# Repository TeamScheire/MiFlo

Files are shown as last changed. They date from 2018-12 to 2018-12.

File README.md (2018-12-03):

# Team Scheire MiFlo's voor Minne en Flo

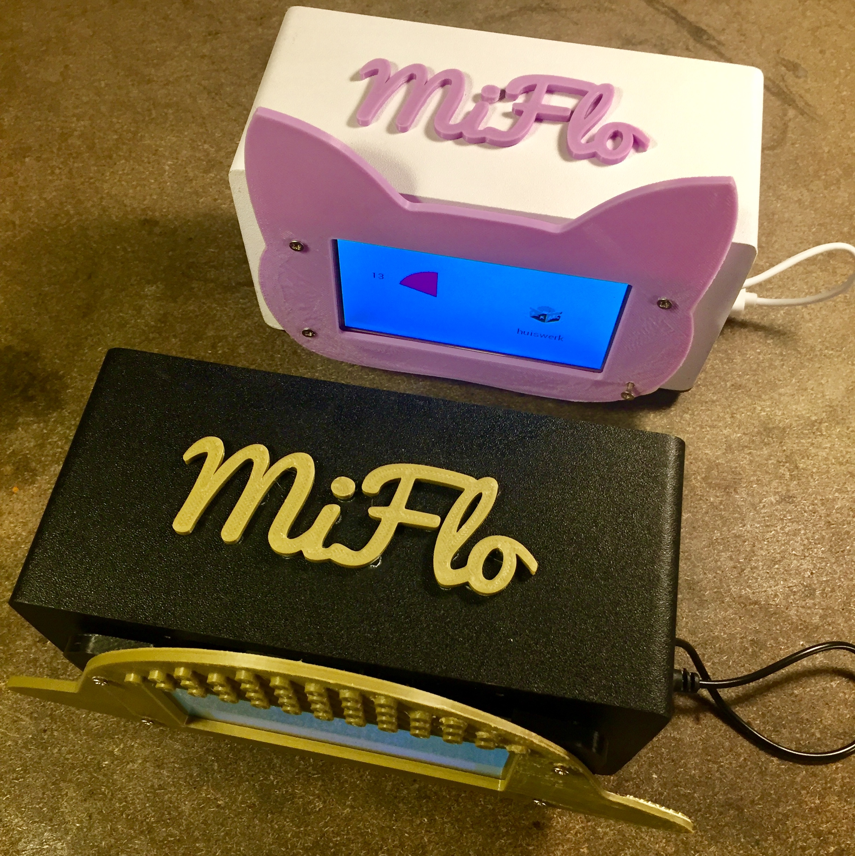
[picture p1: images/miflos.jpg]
Miflo's


Met hun MiFlo kregen Minne en Flo hun eigen persoonlijke digitale assistent.

De MiFlo is een wekker die aan het internet hangt. Mama en papa kunnen via chat of hun online kalender todo's, herinneringen, wekkers of time-timers klaarzetten voor de kinderen.

Door opdrachtjes uit te voeren krijgen de kinderen punten en "gamifyen" we hun dagdagelijkse schema.

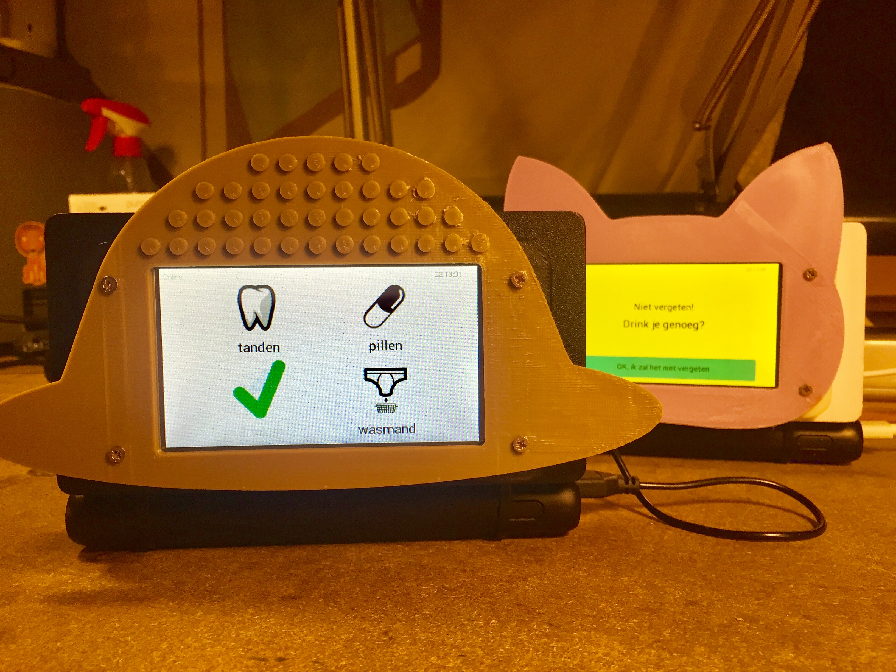
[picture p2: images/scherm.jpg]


Deze repository bevat alle onderdelen die je nodig hebt om zelf een MiFlo te bouwen. 

Een beetje handigheid met Arduino's en elektronische componenten is wel nodig als je zelf een miflo wekker wil maken.

* Onder [hardware](./hardware) kan je een BOM vinden van de materialen die gebruikt werden. Het bevat ook het PCB design en de files om de 3D prints te maken.
* Onder [arduino](./arduino) kan je de code vinden die op de MiFlo's draait. 
* Onder [assets](./assets) vind je de iconen en geluiden die op de SD kaart van de MiFlo staan.
* Onder [backend](./backend) vind je de code die de MiFlo's vanuit het internet controleert. Je kan met Telegram opdrachten naar de MiFlo sturen. Of je kan in Google calendar opdrachten klaarzetten die dan elke 5 minuten worden opgehaald en doorgegeven worden aan de MiFlo's.

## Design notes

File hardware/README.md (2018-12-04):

# Hardware voor de MiFlo

De hardware in de MiFlo is opgebouwd op eenvoudig verkrijgbare modules:

* Een [Adafruit Feather HUZZAH](https://learn.adafruit.com/adafruit-feather-huzzah-esp8266) wordt gebruikt als de "Arduino". Deze bevat een ESP8266 chip waarmee we ook WiFi kunnen gebruiken
* De [Gameduino 3](http://excamera.com/sphinx/gameduino3/) is een touchscreen dat je makkelijk op een Arduino kan monteren en aansturen. Het kan ook geluiden of filmpjes spelen van een SD kaart. Bijvoorbeeld [hier te koop](https://www.watterott.com/de/Gameduino-3).
* Met een [RTC breakout board](https://www.adafruit.com/product/3295) kunnen we de tijd bijhouden als de MiFlo geen stroom heeft.
* Een [geluidsversterker](https://www.adafruit.com/product/1752) zorgt ervoor dat de audio krachtig genoeg uit de speakers komt.
* We bouwden alles in een [SoundLogic draagbare speaker](https://www.action.com/nl-be/p/soundlogic-draagbare-speaker/) van den Action.

We ontwierpen zelf een PCB die deze componenten allemaal bij elkaar brengt, deze vind je (als `.brd` en `.sch` files voor Autodesk EAGLE) in deze repository. Met de PCB kan je zowel een klassieke Arduino of een Adafruit Feather verbinden met het Gameduino touchscreen.

Om de MiFlo mooi te bevestigen printten we kittenoortjes voor Minne en een Lego-helm voor Flo. Samen met 2 clips kan je de MiFlo zo bevestigen in de draagbare speakerkast. Je vindt deze STL files om zelf te printen als `kat.stl`, `legohelm.stl` en `clip.stl`.

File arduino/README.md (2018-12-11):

# Arduino code voor de MiFlo

Deze code is geschreven voor een [Adafruit Feather HUZZAH ESP8266](https://learn.adafruit.com/adafruit-feather-huzzah-esp8266) in combinatie met een [gameduino touchscreen](https://www.watterott.com/en/Gameduino-3). 

Bekijk in de [hardware](../hardware) folder van dit project de volledige hardware lijst.

## Configuratie en setup

Alle details over de Adafruit Feather HUZZAH ESP8266 staan op [de site van adafruit](https://learn.adafruit.com/adafruit-feather-huzzah-esp8266/using-arduino-ide).

Kopiëer het bestand `settings_example.h` naar `settings.h` en vul alle parameters in.

Je hebt ook de volgende libraries nodig:

* [gameduino](https://github.com/jamesbowman/gd2-lib)
* arduino EEPROM library
* [RTC](https://github.com/adafruit/RTClib) library.
* [ArduinoJson](https://github.com/bblanchon/ArduinoJson)

In de gameduino library moet je enkele aanpassingen doen in de GD2.file:

*  Voeg
	
	```
	#define D8  0
	#define D9  16
	```
	toe net voor de lijn `#define CS D8`.
* Zoek naar `#define L2` en `#define L4` en comment deze lijnen.

De arduino code gaat ervanuit dat je de geconverteerde [assets](../assets) mee op de sd kaart gezet hebt.

In de code wordt bv de header-file `m_cool.h` geladen.

```
#include "m_cool.h"
```

Daarnaast worden ook alle pictogrammen geladen:

```
void load_jpgs() 
{
	GD.BitmapHandle(BRIL_JPG);
	GD.cmd_loadimage(ASSETS_END, 0);
	GD.load("BRIL.jpg");

	...
	
}
```

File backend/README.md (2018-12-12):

# MiFLo backend

These two tools send commands to the MiFlo. One is a Google Calendar script that sends the 5 upcoming events on a calendar to the MiFlo, to be cached and executed when planned. The second is a Telegram bot that listens to commands over Telegram and forwards them to the MiFLo.

## Calendar

Follow ruby calendar quickstart at [https://developers.google.com/calendar/quickstart/ruby] (https://developers.google.com/calendar/quickstart/ruby) to obtain credentials in the form of a `client_secret.json` file so you can run the example:

`ruby calendar.rb -c CALENDAR_ID -p PERSON_NAME -h MQTT_BROKER`

## Telegram bot

Get a Telegram bot up and running, acquire the token and run the MiFlo bot:

`ruby telegram_bot.rb -h MQTT_BROKER -t TELEGRAM_BOT_TOKEN -p PERSON_NAME`

## Example installation rapsberry pi

The backend can run on any server, but here is a small example on how to do it on a raspberry pi:

* Install raspbian [https://www.raspberrypi.org/downloads/raspbian/](https://www.raspberrypi.org/downloads/raspbian/)
* Using `sudo raspi-config` you can adapt some basic settings (e.g. enable ssh, change hostname, update, ...), do not forget to correct the timezone
* `sudo apt-get update`
* install git: `sudo apt-get install git`
* clone the repo `git clone https://github.com/TeamScheire/MiFlo.git`
* `cd MiFlo/backend`
* install ruby: 
 ```
 sudo apt-get install ruby
 sudo gem install bundler
 bundle install
 ```
* install mosquitto broker:
 ```
 sudo wget https://repo.mosquitto.org/debian/mosquitto-repo.gpg.key
 sudo apt-key add mosquitto-repo.gpg.key
 cd /etc/apt/sources.list.d/
 sudo wget http://repo.mosquitto.org/debian/mosquitto-stretch.list
 sudo apt-get update
 sudo apt-get install mosquitto mosquitto-clients
 ```

* get the calender up and running
 * Follow ruby calendar quickstart at [https://developers.google.com/calendar/quickstart/ruby] (https://developers.google.com/calendar/quickstart/ruby) to obtain credentials in the form of a `client_secret.json`
 * copy/rename the `client_secret.json` to the backend folder, e.g. using `scp`
 * test the calender script `ruby calendar.rb -c CALENDAR_ID -p PERSON_NAME -h localhost` 
  where CALENDER_ID can be found in the settings of the google calender
 * add it to crontab `crontab -e`
 * e.g. every 5 minutes: `*/5 * * * * script -c "cd /home/pi/MiFlo/backend/; ruby calendar.rb -c CALENDAR_ID -p PERSON_NAME -h localhost" /home/pi/MiFlo/backend/calendar.log`
* get the telegram bot up and running
 * create a new bot: `https://core.telegram.org/bots#6-botfather` 
 * test the script `ruby telegram_bot.rb -h localhost -t TELEGRAM_BOT_TOKEN -p PERSON_NAME
 * start on startup: `sudo nano /etc/rc.local`
 * add line `ruby /home/pi/MiFlo/backend/telegram_bot.rb -h localhost -t TELEGRAM_BOT_TOKEN -p PERSON_NAME & > /home/pi/MiFlo/backend/telegram_bot.log  2>&1`

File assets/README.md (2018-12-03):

# MiFlo assets

De assets (afbeeldingen en geluidsfragmenten) voor op de SD card van de MiFlo.

Om deze te kunnen gebruiken, moeten deze geconverteerd worden. 
In deze readme staan de instructies voor linux/mac.

## Conversie van de afbeeldingen

Via het `convert` pakket. Bijvoorbeeld te installeren via apt (linux) of [brew](https://brew.sh/index_nl) (mac).

Zie [convert.sh](convert.sh) voor een bash script.

## Conversion van de audio

de [gameduino2 library](https://github.com/jamesbowman/gd2-lib) heeft de nodige conversietools aan boord om deze audio om te zetten in zogenaamde headers. 

### install gameduino library

```
sudo easy_install -U gameduino2
``` 

### generate headers with following code

```
gd3asset -3 -f all.gd2 -o all.h f_bol.wav f_uitst.wav g_cool.wav g_formid.wav g_machti.wav g_stieva.wav g_woew.wav m_flink2.wav m_spinne.wav f_dduim.wav f_wauw.wav g_dduim2.wav g_goed.wav g_muppet.wav g_super.wav g_woop.wav m_flink3.wav m_super.wav f_go.wav g_allez.wav g_demax.wav g_goedzo.wav g_prima.wav g_tsjing.wav g_zogoed.wav m_gewel.wav f_komaan.wav g_bol.wav g_fantas.wav g_hopla.wav g_scool.wav g_wiii.wav m_flink.wav m_goed.wav
gd3asset -3 -f minne.gd2 -o minne.h m_flink3.wav m_super.wav m_gewel.wav m_flink.wav m_goed.wav m_flink2.wav m_spinne.wav
gd3asset -3 -f flo.gd2 -o flo.h f_dduim.wav f_wauw.wav f_bol.wav f_uitst.wav f_go.wav f_komaan.wav
gd3asset -3 -f genflo.gd2 -o genflo.h f_dduim.wav f_wauw.wav f_bol.wav f_uitst.wav f_go.wav f_komaan.wav g_cool.wav g_formid.wav g_machti.wav g_stieva.wav g_woew.wav g_dduim2.wav g_goed.wav g_muppet.wav g_super.wav g_woop.wav g_allez.wav g_demax.wav g_goedzo.wav g_prima.wav g_tsjing.wav g_zogoed.wav g_bol.wav g_fantas.wav g_hopla.wav g_scool.wav g_wiii.wav
gd3asset -3 -f genminne.gd2 -o genminne.h g_cool.wav g_formid.wav g_machti.wav g_stieva.wav g_woew.wav g_dduim2.wav g_goed.wav g_muppet.wav g_super.wav g_woop.wav g_allez.wav g_demax.wav g_goedzo.wav g_prima.wav g_tsjing.wav g_zogoed.wav g_bol.wav g_fantas.wav g_hopla.wav g_scool.wav g_wiii.wav m_flink3.wav m_super.wav m_gewel.wav m_flink.wav m_goed.wav m_flink2.wav m_spinne.wav
```

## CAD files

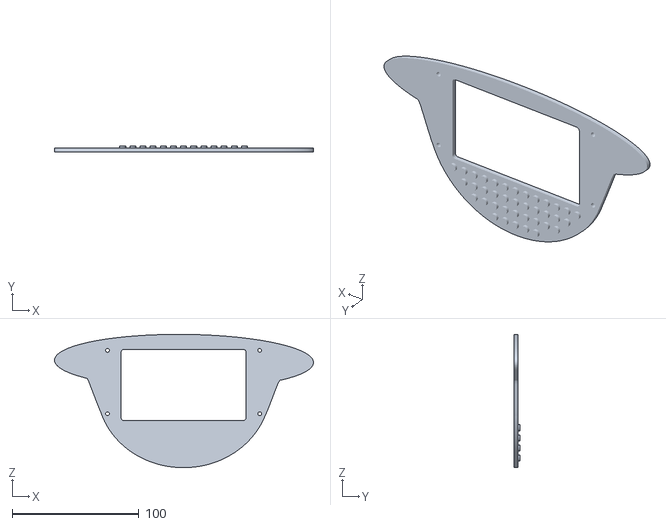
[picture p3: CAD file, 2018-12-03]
hardware/legohelm.stl
204.3 x 4.80 x 105.1

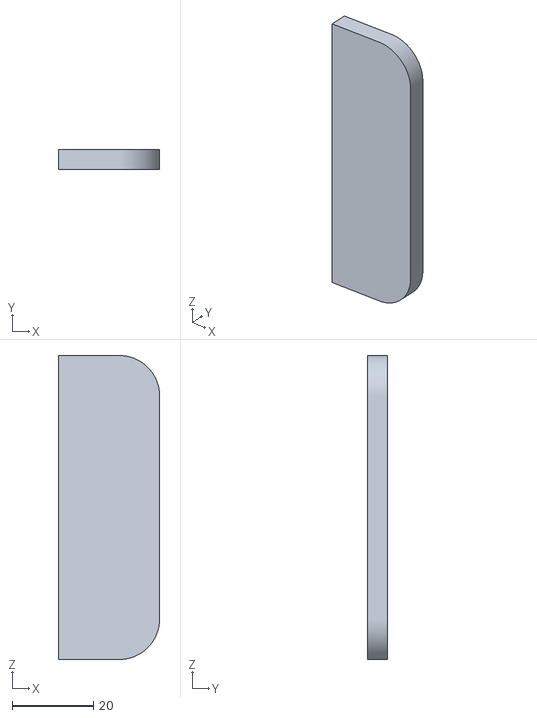
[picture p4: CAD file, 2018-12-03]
hardware/clip.stl
25.0 x 5.00 x 75.0

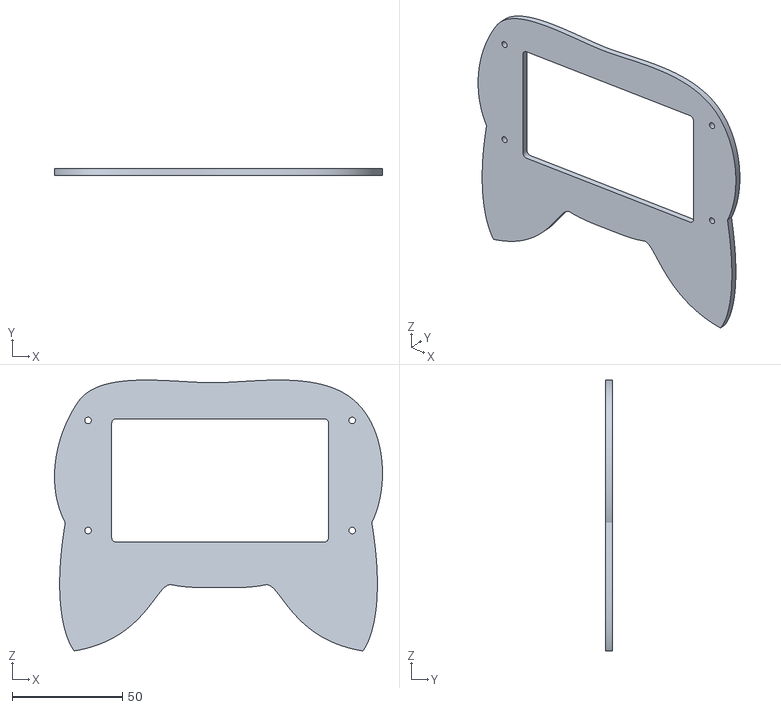
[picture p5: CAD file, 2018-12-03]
hardware/kat.stl
149.0 x 3.00 x 123.1

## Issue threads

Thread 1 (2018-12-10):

Ontbrekende libraries in Eagle

Sharp6, 2018-12-10:
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

Ik probeer de miflo.brd in Eagle te openen om de hardware connecties beter te begrijpen. Eagle klaagt hierbij over enkele missing libraries (FriedCamp en Anthony's components). Kunnen deze nog voorzien worden, of is de impact hiervan beperkt?

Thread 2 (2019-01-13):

Printing/Etching of the PCB

yhellowt, 2019-01-13:
Wat is de meest eenvoudige manier om de PCB te maken?

mstrdigi, 2019-03-20:
Hey, ik heb deze besteld bij Aisler. Het bordje zou deze week aankomen.
Ik heb het project op publiek gezet, zodat je deze ook kan bekijken/bestellen.
https://aisler.net/p/PNIKGYLV

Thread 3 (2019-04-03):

Link soundversterker verwijst naar verkeerde type?

RobinR1, 2019-04-03:
In [hardware/README.md](https://github.com/TeamScheire/MiFlo/blob/master/hardware/README.md) wordt verwezen naar een [Stereo 20W Class D Audio Amplifier - MAX9744](https://www.adafruit.com/product/1752) maar de voorziene pin-layout op de PCB komt exact overeen met een [Adafruit Mono 2.5W Class D Audio Amplifier - PAM8302](https://www.adafruit.com/product/2130).
Is de link in [hardware/README.md](https://github.com/TeamScheire/MiFlo/blob/master/hardware/README.md) verkeerd?

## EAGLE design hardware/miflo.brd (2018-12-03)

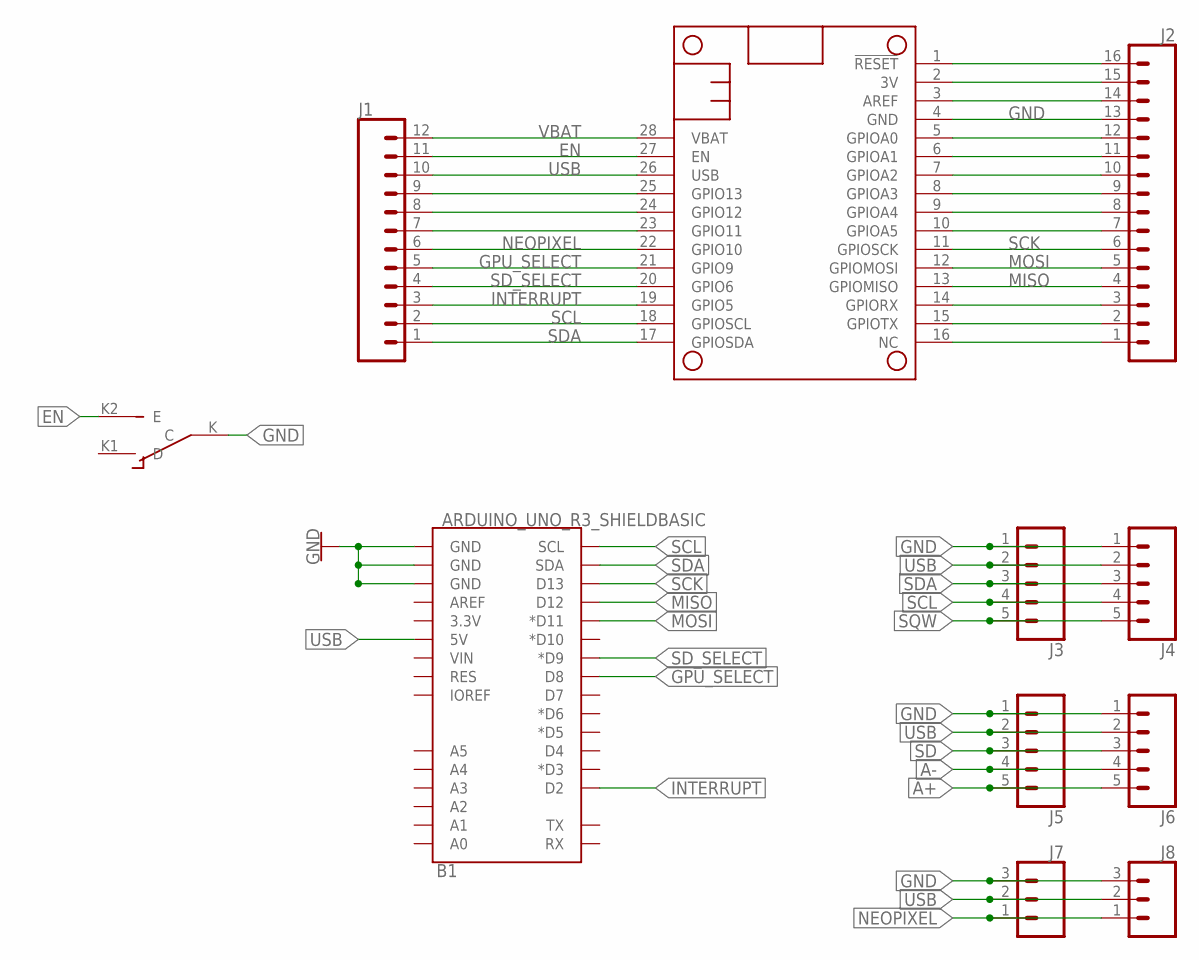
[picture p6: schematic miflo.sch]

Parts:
B1: ARDUINO_UNO_R3_SHIELDBASIC; UNO_R3_SHIELD
J1: CONN_12; 1X12
J2: CONN_16; 1X16
J3, J4, J5, J6: CONN_05; 1X05
J7, J8: CONN_03; 1X03
MS2: FEATHERWING_NODIM; FEATHERWING_DIM
U$11: SLIDE-SWITCH

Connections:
3V: J2.15, MS2.2 (3V)
A+: J5.5, J6.5
A-: J5.4, J6.4
EN: J1.11, MS2.27 (EN), U$11.K2 (E)
GND: B1.GND@0 (GND), B1.GND@1 (GND), B1.GND@2 (GND), J2.13, J3.1, J4.1, J5.1, J6.1, J7.3, J8.3, MS2.4 (GND), U$11.K (C)
GPU_SELECT: B1.D8, J1.5, MS2.21 (GPIO9)
INTERRUPT: B1.D2, J1.3, MS2.19 (GPIO5)
MISO: B1.D12, J2.4, MS2.13 (GPIOMISO)
MOSI: B1.D11 (*D11), J2.5, MS2.12 (GPIOMOSI)
unnamed: J1.9, MS2.25 (GPIO13)
unnamed: J1.8, MS2.24 (GPIO12)
unnamed: J1.7, MS2.23 (GPIO11)
unnamed: J2.1, MS2.16 (NC)
unnamed: J2.2, MS2.15 (GPIOTX)
unnamed: J2.3, MS2.14 (GPIORX)
unnamed: J2.7, MS2.10 (GPIOA5)
unnamed: J2.8, MS2.9 (GPIOA4)
unnamed: J2.9, MS2.8 (GPIOA3)
unnamed: J2.10, MS2.7 (GPIOA2)
unnamed: J2.11, MS2.6 (GPIOA1)
unnamed: J2.12, MS2.5 (GPIOA0)
unnamed: J2.14, MS2.3 (AREF)
unnamed: J2.16, MS2.1 (!RESET)
NEOPIXEL: J1.6, J7.1, J8.1, MS2.22 (GPIO10)
SCK: B1.D13, J2.6, MS2.11 (GPIOSCK)
SCL: B1.SCL, J1.2, J3.4, J4.4, MS2.18 (GPIOSCL)
SD: J5.3, J6.3
SDA: B1.SDA, J1.1, J3.3, J4.3, MS2.17 (GPIOSDA)
SD_SELECT: B1.D9 (*D9), J1.4, MS2.20 (GPIO6)
SQW: J3.5, J4.5
USB: B1.5V, J1.10, J3.2, J4.2, J5.2, J6.2, J7.2, J8.2, MS2.26 (USB)
VBAT: J1.12, MS2.28 (VBAT)

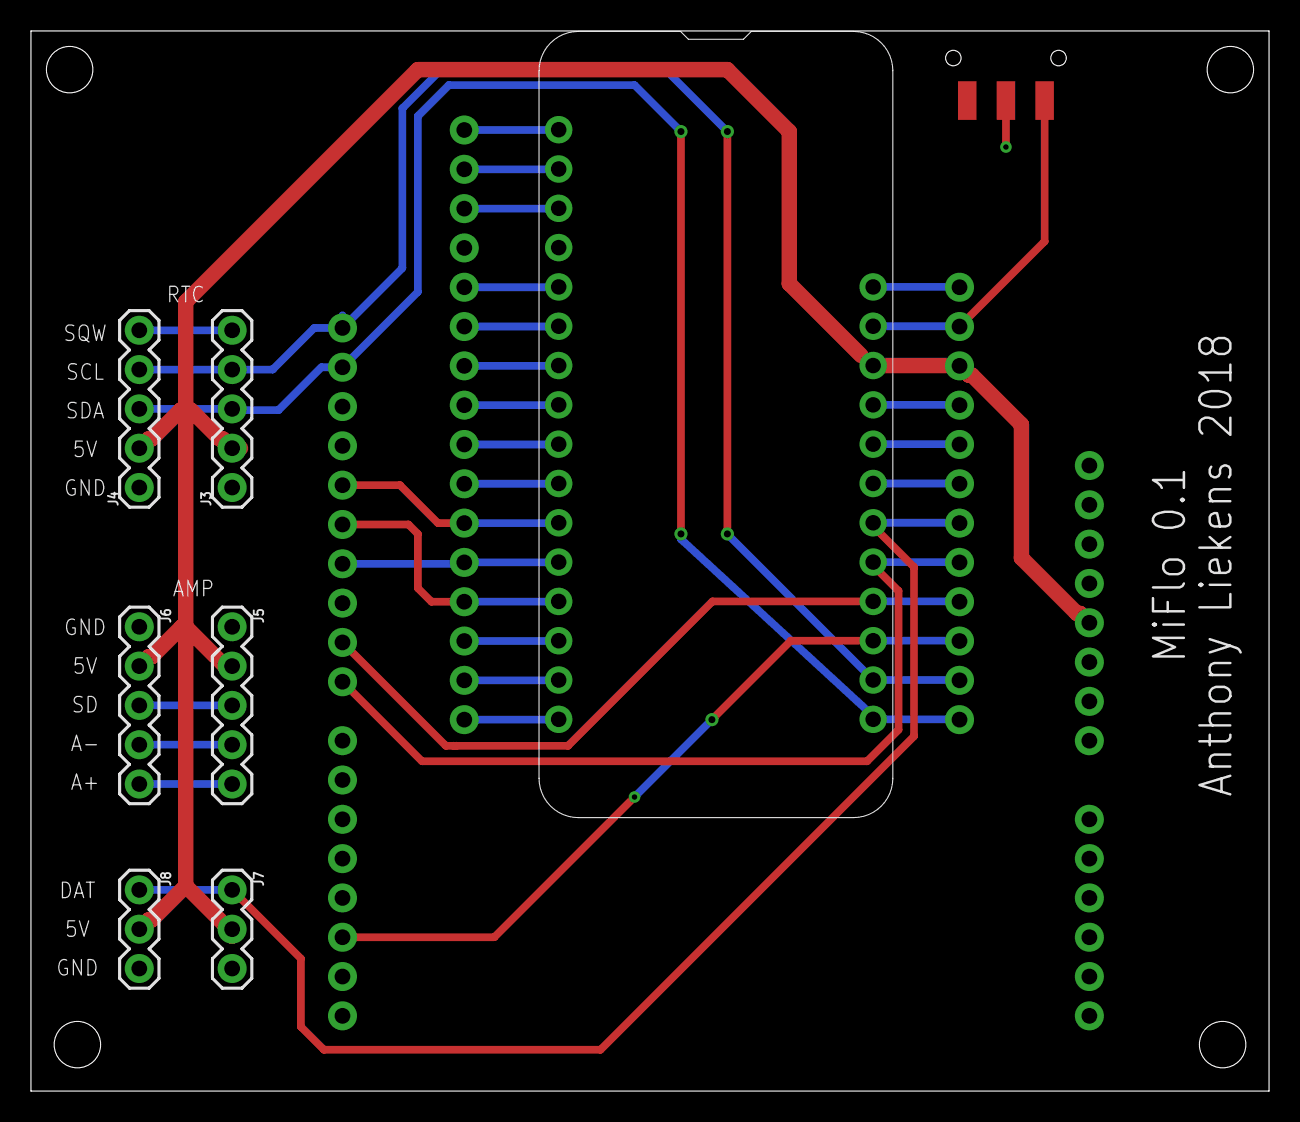
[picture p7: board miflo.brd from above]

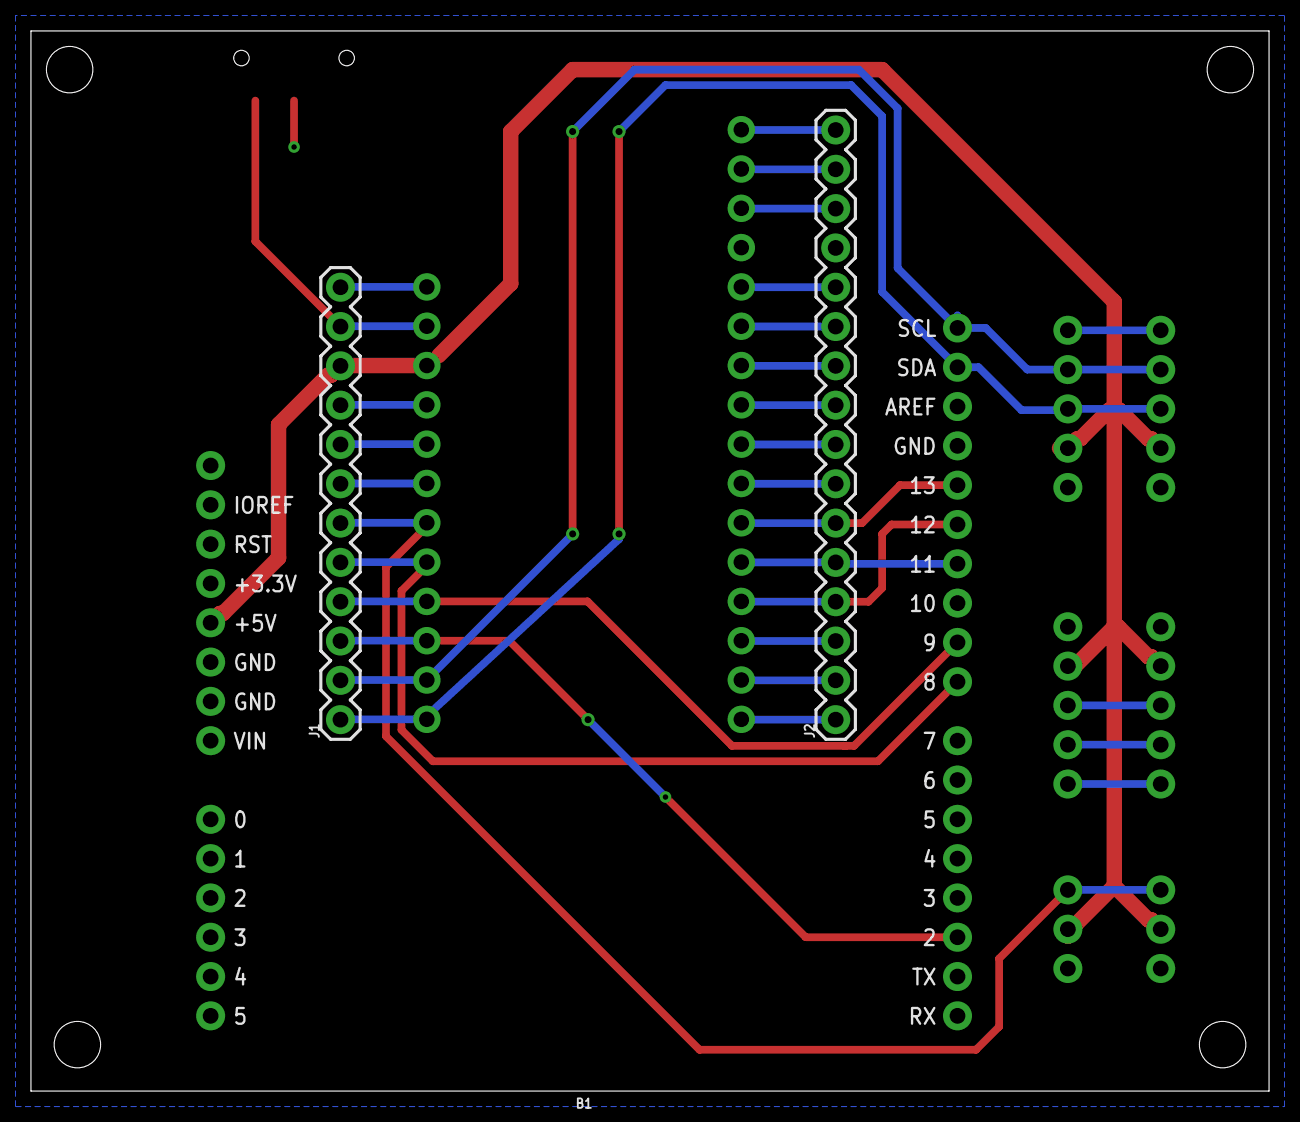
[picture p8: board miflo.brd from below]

Board: 2 copper layers, 80.0 x 68.5 mm, 11 parts (3 on the bottom side), 32 nets.

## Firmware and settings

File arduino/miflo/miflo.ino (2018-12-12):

#define SECONDS_PER_MINUTE 60

// THE LINE BELOW SHOULD OVERRIDE PUBSUBCLIENT'S BUT DOESN'T REALLY DO IT ...
#define MQTT_MAX_PACKET_SIZE 1024

#include <EEPROM.h>
#include <SPI.h>
#include <GD2.h>

#include "m_cool.h"

// notes in the melody:
int melody[] = {
  NOTE_C4, NOTE_G3, NOTE_G3, NOTE_A3, NOTE_G3, 0, NOTE_B3, NOTE_C4
};

// note durations: 4 = quarter note, 8 = eighth note, etc.:
int noteDurations[] = {
  4, 8, 8, 4, 4, 4, 4, 4
};



#include "settings.h"

#include <ESP8266WiFi.h>
WiFiClient espClient;

#include <PubSubClient.h>
PubSubClient client(espClient);

#include <Wire.h>
#include "RTClib.h"
RTC_DS1307 rtc;

#include <ArduinoJson.h>

#define COLOR_BEIGE 0xffe9ac
#define COLOR_GREEN 0x588751
#define COLOR_RED 0xd41942
#define COLOR_ORANGE 0xff6f25
#define COLOR_YELLOW 0xffc700
#define COLOR_BLUE 0x2b19d4
#define COLOR_BLACK 0x030302
#define COLOR_WHITE 0xffe9e6

#define GOED_AANTAL 16
char* goed[GOED_AANTAL] = { "fantastisch", "buitengewoon", "geweldig", "fenomenaal", "toverachtig", "wonderlijk", "uitstekend", "eersteklas", "opperbest", "excellent", "briljant", "grandioos", "machtig", "sensationeel", "volmaakt", "uitzonderlijk" };
int goed1, goed2;

int points = 1;

enum State { CLOCK_STATE, TIME_TIMER_STATE, FINISHED_STATE, REMINDER_STATE, ALARM_STATE, TODO_STATE, GOED_GEDAAN_STATE, UPCOMING_STATE, SHOW_LOG_STATE };
State state = SHOW_LOG_STATE;
long time_timer = 0;

enum JPG {
  BRIL_JPG,
  DOUCHEN_JPG,
  DRINKEN_JPG,
  HAAR_JPG,
  HUISWERK_JPG,
  KAKA_JPG,
  KINE_JPG,
  KLUSSEN_JPG,
  LEGOPRUM_JPG,
  LEZEN_JPG,
  NAGELS_JPG,
  NOPANIC_JPG,
  PILLEN_JPG,
  PIPIKAKA_JPG,
  POMPEN_JPG,
  PYJAMA_JPG,
  TANDEN_JPG,
  UITMEST_JPG,
  WASMAND_JPG,
  UNKNOWN_JPG
};

int todo_jpgs[ 4 ] = { TANDEN_JPG, PYJAMA_JPG, UITMEST_JPG, WASMAND_JPG };
String todo_texts[ 4 ] = { "tanden poetsen", "pyjama ophangen", "bed uitmesten", "ondergoed in de was" };
bool todo_done[ 4 ] = { false, false, false, false };

char current_job_string[200] = "";

char* string2char(String s) {
  if (s.length() != 0) {
    char *p = const_cast<char*>(s.c_str());
    return p;
  }
}

char* int2char(int n) {
  char s[16];
  itoa(n, s, 10);
  return s;
}

#include <vector>
std::vector< String > log_history;
void add_log( String message ) {
  Serial.println( message );
  log_history.push_back( message );
  while ( log_history.size() > 16 ) {
    log_history.erase( log_history.begin() );
  }
  if ( state == SHOW_LOG_STATE ) {
    GD.ClearColorRGB(COLOR_BLACK);
    GD.Clear();
    GD.ColorRGB(COLOR_BEIGE);
    show_log();
    GD.swap();
  }
}

void show_log() {
  int x = 0;
  for ( std::vector< String >::iterator i = log_history.begin(); i != log_history.end(); i++ ) {
    GD.cmd_text(5, 25 + x * 14, 20, 0, string2char(*i));
    x++;
  }
}

void playmelody() {
  // iterate over the notes of the melody:
  for (int thisNote = 0; thisNote < 8; thisNote++) {

    // to calculate the note duration, take one second
    // divided by the note type.
    //e.g. quarter note = 1000 / 4, eighth note = 1000/8, etc.
    int noteDuration = 1000 / noteDurations[thisNote];
    tone(15, melody[thisNote], noteDuration);

    // to distinguish the notes, set a minimum time between them.
    // the note's duration + 30% seems to work well:
    int pauseBetweenNotes = noteDuration * 1.10;
    delay(pauseBetweenNotes);
    // stop the tone playing:
    noTone(15);
  }
}

//int samplebases[26] = {F_DDUIM, F_WAUW, F_BOL, F_UITST, F_GO, F_KOMAAN, G_COOL, G_FORMID, G_MACHTI, G_STIEVA, G_WOEW, G_DDUIM2, G_GOED, G_SUPER, G_WOOP, G_ALLEZ, G_DEMAX, G_GOEDZO, G_PRIMA, G_TSJING, G_ZOGOED, G_BOL, G_FANTAS, G_HOPLA, G_SCOOL, G_WIII};
//int samplefreqs[26] = {F_DDUIM_FREQ, F_WAUW_FREQ, F_BOL_FREQ, F_UITST_FREQ, F_GO_FREQ, F_KOMAAN_FREQ, G_COOL_FREQ, G_FORMID_FREQ, G_MACHTI_FREQ, G_STIEVA_FREQ, G_WOEW_FREQ, G_DDUIM2_FREQ, G_GOED_FREQ, G_SUPER_FREQ, G_WOOP_FREQ, G_ALLEZ_FREQ, G_DEMAX_FREQ, G_GOEDZO_FREQ, G_PRIMA_FREQ, G_TSJING_FREQ, G_ZOGOED_FREQ, G_BOL_FREQ, G_FANTAS_FREQ, G_HOPLA_FREQ, G_SCOOL_FREQ, G_WIII_FREQ};
//int samplelengths[26] = {F_DDUIM_LENGTH, F_WAUW_LENGTH, F_BOL_LENGTH, F_UITST_LENGTH, F_GO_LENGTH, F_KOMAAN_LENGTH, G_COOL_LENGTH, G_FORMID_LENGTH, G_MACHTI_LENGTH, G_STIEVA_LENGTH, G_WOEW_LENGTH, G_DDUIM2_LENGTH, G_GOED_LENGTH, G_SUPER_LENGTH, G_WOOP_LENGTH, G_ALLEZ_LENGTH, G_DEMAX_LENGTH, G_GOEDZO_LENGTH, G_PRIMA_LENGTH, G_TSJING_LENGTH, G_ZOGOED_LENGTH, G_BOL_LENGTH, G_FANTAS_LENGTH, G_HOPLA_LENGTH, G_SCOOL_LENGTH, G_WIII_LENGTH};
int samplebases[20] = {G_COOL, G_FORMID, G_MACHTI, G_STIEVA, G_WOEW, G_DDUIM2, G_GOED, G_SUPER, G_WOOP, G_ALLEZ, G_DEMAX, G_GOEDZO, G_PRIMA, G_TSJING, G_ZOGOED, G_BOL, G_FANTAS, G_HOPLA, G_SCOOL, G_WIII};
int samplefreqs[20] = {G_COOL_FREQ, G_FORMID_FREQ, G_MACHTI_FREQ, G_STIEVA_FREQ, G_WOEW_FREQ, G_DDUIM2_FREQ, G_GOED_FREQ, G_SUPER_FREQ, G_WOOP_FREQ, G_ALLEZ_FREQ, G_DEMAX_FREQ, G_GOEDZO_FREQ, G_PRIMA_FREQ, G_TSJING_FREQ, G_ZOGOED_FREQ, G_BOL_FREQ, G_FANTAS_FREQ, G_HOPLA_FREQ, G_SCOOL_FREQ, G_WIII_FREQ};
int samplelengths[20] = {G_COOL_LENGTH, G_FORMID_LENGTH, G_MACHTI_LENGTH, G_STIEVA_LENGTH, G_WOEW_LENGTH, G_DDUIM2_LENGTH, G_GOED_LENGTH, G_SUPER_LENGTH, G_WOOP_LENGTH, G_ALLEZ_LENGTH, G_DEMAX_LENGTH, G_GOEDZO_LENGTH, G_PRIMA_LENGTH, G_TSJING_LENGTH, G_ZOGOED_LENGTH, G_BOL_LENGTH, G_FANTAS_LENGTH, G_HOPLA_LENGTH, G_SCOOL_LENGTH, G_WIII_LENGTH};

void sample() {
  digitalWrite(15, HIGH);
  GD.play(UNMUTE);
  uint32_t base, len, freq;
  int i = rand() % 20;
  base = samplebases[i];
  len = samplelengths[i];
  freq = samplefreqs[i];
  GD.sample(base, len, freq, ADPCM_SAMPLES);
  delay(2000 * len / freq);
  GD.play(MUTE);
  digitalWrite(15, LOW);
}

void jingle( int n = 0 ) {
  digitalWrite(15, HIGH);
  if ( n == 0 ) {
    GD.play( MUSICBOX, 60 );
    delay(250);
    GD.play( MUSICBOX, 60 );
    delay(500);
    GD.play( MUTE );
  } else if ( n == 1 ) {
    GD.play( MUSICBOX, 60 );
    delay(250);
    GD.play( MUSICBOX, 60 );
    delay(250);
    GD.play( MUSICBOX, 60 );
    delay(500);
    GD.play( MUTE );
  } else if ( n == 2 ) {
    GD.play( PIANO, 55 );
    delay(250);
    GD.play( PIANO, 64 );
    delay(250);
    GD.play( PIANO, 60 );
    delay(500);
    GD.play( MUTE );
  }
  digitalWrite(15, LOW);
}

#include <map>
std::map< int, String > cache;

void parse_command( char* json ) {
  StaticJsonBuffer<1024> jsonBuffer;

  JsonObject& root = jsonBuffer.parseObject(json);

  const char* type = root["type"];

  if ( strcmp( type, "reset" ) == 0 ) {
    add_log("Running reset");
    state = CLOCK_STATE;
  } else if ( strcmp( type, "audio" ) == 0 ) {
    add_log("Playing audio");
    sample();
  } else if ( strcmp( type, "settime" ) == 0 ) {
    add_log("Setting the clock");
    int hour = root["hour"];
    int minute = root["minute"];
    String timestring = format_time( hour, minute, 0 );
    rtc.adjust(DateTime(__DATE__, string2char(timestring)));
  } else if ( strcmp( type, "events" ) == 0 ) {
    add_log("Caching events");
    cache.clear();
    for ( int i = 0; i < root["events"].size(); i++ ) {
      int hour = root["events"][i]["hour"];
      int minute = root["events"][i]["minute"];
      int second = root["events"][i]["second"];
      int time = hour * 10000 + minute * 100 + second;
      const char* task = root["events"][i]["task"];
      cache[ time ] = task;
    }
  } else if ( strcmp( type, "log" ) == 0 ) {
    add_log("Showing log");
    state = SHOW_LOG_STATE;
  } else if ( strcmp( type, "plus" ) == 0 ) {
    add_log("Running plus");
    points++;
    sample();
  } else if ( strcmp( type, "min" ) == 0 ) {
    add_log("Running min");
    points--;
  } else if ( strcmp( type, "todo" ) == 0 ) {
    add_log("Running todo");
    todo_texts[ 0 ] = (const char*)root["job"][0];
    todo_jpgs[ 0 ] = job2jpg( todo_texts[ 0 ] );
    todo_texts[ 1 ] = (const char*)root["job"][1];
    todo_jpgs[ 1 ] = job2jpg( todo_texts[ 1 ] );
    todo_texts[ 2 ] = (const char*)root["job"][2];
    todo_jpgs[ 2 ] = job2jpg( todo_texts[ 2 ] );
    todo_texts[ 3 ] = (const char*)root["job"][3];
    todo_jpgs[ 3 ] = job2jpg( todo_texts[ 3 ] );
    todo_done[ 0 ] = ( todo_texts[ 0 ] == "" );
    todo_done[ 1 ] = ( todo_texts[ 1 ] == "" );
    todo_done[ 2 ] = ( todo_texts[ 2 ] == "" );
    todo_done[ 3 ] = ( todo_texts[ 3 ] == "" );
    state = TODO_STATE;
  } else if ( strcmp( type, "timetimer" ) == 0 ) {
    add_log("Running timetimer");
    int minutes = root["minutes"];
    Serial.print( "minutes: " );
    Serial.println( minutes );
    const char* job = root["job"];
    strcpy(current_job_string, job);
    add_log( job );
    DateTime now = rtc.now();
    time_timer = now.unixtime() + minutes * SECONDS_PER_MINUTE;
    state = TIME_TIMER_STATE;
    jingle(1);
  } else if ( strcmp( type, "reminder" ) == 0 ) {
    add_log("Running reminder");
    const char* job = root["message"];
    strcpy(current_job_string, job);
    state = REMINDER_STATE;
  } else if ( strcmp( type, "alarm" ) == 0 ) {
    add_log("Running alarm");
    const char* job = root["message"];
    strcpy(current_job_string, job);
    state = ALARM_STATE;
  }
}

void mqttCallback(char* topic, byte* payload, unsigned int length) {
  add_log("Incoming MQTT message on topic:");
  add_log(topic);
  add_log("MQTT message:");
  char json[ length ];
  for (int i = 0; i < length; i++) {
    Serial.print((char)payload[i]);
    json[i] = (char)payload[i];
  }
  add_log( json );
  parse_command(json);
}

long lastMQTTReconnectAttempt = 0;
void mqttOnlineCheck() {
  if (!client.connected()) {
    long now = millis();
    if (now - lastMQTTReconnectAttempt > 5000) {
      lastMQTTReconnectAttempt = now;
      client.setServer(mqttServer, mqttPort);
      client.setCallback(mqttCallback);

      add_log("Connecting to MQTT ...");

      if (client.connect(mqttClient)) {

        add_log("Connected to MQTT");
        client.subscribe(mqttTopic);

      } else {

        add_log("MQTT connect failed");
        // add_log(client.state());

      }
    }
  }
}

void load_jpgs()
{

  GD.BitmapHandle(BRIL_JPG);
  GD.cmd_loadimage(ASSETS_END, 0);
  GD.load("BRIL.jpg");
  GD.BitmapHandle(DOUCHEN_JPG);
  GD.cmd_loadimage(-1, 0);
  GD.load("DOUCHEN.jpg");
  GD.BitmapHandle(DRINKEN_JPG);
  GD.cmd_loadimage(-1, 0);
  GD.load("DRINKEN.jpg");
  GD.BitmapHandle(HAAR_JPG);
  GD.cmd_loadimage(-1, 0);
  GD.load("HAAR.jpg");
  GD.BitmapHandle(HUISWERK_JPG);
  GD.cmd_loadimage(-1, 0);
  GD.load("HUISWERK.jpg");
  GD.BitmapHandle(KAKA_JPG);
  GD.cmd_loadimage(-1, 0);
  GD.load("KAKA.jpg");
  GD.BitmapHandle(KINE_JPG);
  GD.cmd_loadimage(-1, 0);
  GD.load("KINE.jpg");
  GD.BitmapHandle(KLUSSEN_JPG);
  GD.cmd_loadimage(-1, 0);
  GD.load("KLUSSEN.jpg");
  GD.BitmapHandle(LEGOPRUM_JPG);
  GD.cmd_loadimage(-1, 0);
  GD.load("LEGOPRUM.jpg");
  GD.BitmapHandle(LEZEN_JPG);
  GD.cmd_loadimage(-1, 0);
  GD.load("LEZEN.jpg");
  GD.BitmapHandle(NAGELS_JPG);
  GD.cmd_loadimage(-1, 0);
  GD.load("NAGELS.jpg");
  GD.BitmapHandle(NOPANIC_JPG);
  GD.cmd_loadimage(-1, 0);
  GD.load("NOPANIC.jpg");
  GD.BitmapHandle(PILLEN_JPG);
  GD.cmd_loadimage(-1, 0);
  GD.load("PILLEN.jpg");
  GD.BitmapHandle(PIPIKAKA_JPG);
  GD.cmd_loadimage(-1, 0);
  GD.load("PIPIKAKA.jpg");
  GD.BitmapHandle(POMPEN_JPG);
  GD.cmd_loadimage(-1, 0);
  GD.load("POMPEN.jpg");
  GD.BitmapHandle(PYJAMA_JPG);
  GD.cmd_loadimage(-1, 0);
  GD.load("PYJAMA.jpg");
  GD.BitmapHandle(TANDEN_JPG);
  GD.cmd_loadimage(-1, 0);
  GD.load("TANDEN.jpg");
  GD.BitmapHandle(UITMEST_JPG);
  GD.cmd_loadimage(-1, 0);
  GD.load("UITMEST.jpg");
  GD.BitmapHandle(WASMAND_JPG);
  GD.cmd_loadimage(-1, 0);
  GD.load("WASMAND.jpg");
  GD.BitmapHandle(UNKNOWN_JPG);
  GD.cmd_loadimage(-1, 0);
  GD.load("UNKNOWN.jpg");
}

void setup() {
  Serial.begin(115200);

  pinMode( 15, OUTPUT );

  Serial.println("Starting gameduino ...");
  GD.begin(GD_STORAGE);
  GD.play( MUTE );
  GD.cmd_setrotate(0);
  GD.cmd_regwrite(REG_VOL_PB, 255);
  GD.cmd_regwrite(REG_VOL_SOUND, 255);

  add_log("Gameduino started");

  add_log("Loading sounds ...");
  LOAD_ASSETS();
  add_log("Sounds loaded");

  add_log("Loading JPGs ...");
  load_jpgs();
  add_log("JPGs loaded");

  WiFi.begin( ssid, password );
  while (WiFi.status() != WL_CONNECTED) {
    delay(500);
    add_log("Connecting to Wifi ...");
  }
  add_log("Connected to WiFi network:");
  add_log(WiFi.SSID());

  mqttOnlineCheck();

  add_log("Starting RTC ...");
  if (! rtc.begin()) {
    add_log("Couldn't find RTC");
    while (1);
  } else {
    add_log("RTC started");
  }

  // set clock to compile time
  // only uncomment if you want to set this date
  // rtc.adjust(DateTime(__DATE__, __TIME__));

  add_log( "MiFlo has booted successfully!" );

  state = CLOCK_STATE;

}

String format_time( int hour, int minute, int second ) {
  return String( hour < 10 ? "0" : "" ) + hour + ( minute < 10 ? ":0" : ":" ) + minute + ( second < 10 ? ":0" : ":" ) + second;
}

String format_time_space( int hour, int minute, int second ) {
  return String( hour < 10 ? "0" : "" ) + hour + ( minute < 10 ? " : 0" : " : " ) + minute + ( second < 10 ? " : 0" : " : " ) + second;
}

String current_time() {
  DateTime now = rtc.now();
  return format_time_space  ( now.hour(), now.minute(), now.second() );
}

int animation_counter = 0;
void show_clock() {

  GD.Begin(POINTS);
  GD.ColorA(64);
  GD.ColorRGB(COLOR_BEIGE);
  for ( int i = 0; i < points; i++ ) {
    GD.PointSize(16 * sqrt( i + 1 ) * 5 );
    GD.Vertex2ii(
      100 * ( cos(animation_counter / float(100 + i * 73 % 101)) + cos(animation_counter / float(100 + i * 101 % 73)) ) + GD.w / 2,
      40 * ( sin(animation_counter / float(100 + i * 103 % 89)) + cos(animation_counter / float(100 + i * 89 % 103)) ) + GD.h / 2
    );
  }
  animation_counter++;

  String time = current_time();
  GD.ColorRGB(COLOR_BEIGE);
  GD.ColorA(128);
  GD.cmd_text(GD.w / 2, GD.h / 2, 31, OPT_CENTER, string2char(time));
  GD.ColorA(255);

  GD.get_inputs();
  switch (GD.inputs.tag) {
    case 210:
      state = UPCOMING_STATE;
      break;
  }

  if ( cache.size() > 0 ) {
    GD.ColorRGB(COLOR_BEIGE);
    GD.cmd_fgcolor(COLOR_BLACK);
    GD.ColorA(128);
    GD.Tag(210);
    GD.cmd_button( 20, GD.h - 40, 20, 20, 20, OPT_FLAT, int2char(cache.size()) );
    GD.ColorA(255);
  }

}

static void clock_ray(int centerx, int centery, int &x, int &y, int r, double i)
{
  uint16_t th = 0x8000 + 65536UL * ( i / 60.0 );
  GD.polar(x, y, r, th);
  x += 16 * centerx;
  y += 16 * centery;
}

void show_time_timer( double minutes, int centerx, int centery, int scale ) {
  int x, y;

  GD.Begin(POINTS);
  GD.ColorRGB(COLOR_BLACK);

  // time-timer labels
  /*const char *labels[] = {"0","55","50","45","40","35","30","25","20","15","10","5"};
    int align[12] = { OPT_CENTERX, 0, 0, 0, OPT_RIGHTX, OPT_RIGHTX, OPT_RIGHTX, 0, 0, 0, 0, 0 };
    for (int i = 0; i < 12; i++) {
    clock_ray(centerx, centery, x, y, 16 * scale, i*5);
    GD.cmd_text(x >> 4, y >> 4, 26, OPT_CENTER, labels[i]);
    }*/
  clock_ray(centerx, centery, x, y, 16 * scale * 1.1, -minutes);
  char minute_str[16];
  itoa((int)(minutes + 0.99), minute_str, 10);
  GD.cmd_text(x >> 4, y >> 4, 28, OPT_CENTER, minute_str);

  // clockface
  GD.LineWidth(8);
  GD.Begin(LINES);
  for (int i = 0; i < 60; i++) {
    if ( i % 5 == 0 ) {
      clock_ray(centerx, centery, x, y, 16 * scale * 0.9, i);
      GD.Vertex2f(x, y);
      clock_ray(centerx, centery, x, y, 16 * scale * 0.8, i);
      GD.Vertex2f(x, y);
    } else {
      clock_ray(centerx, centery, x, y, 16 * scale * 0.9, i);
      GD.Vertex2f(x, y);
      clock_ray(centerx, centery, x, y, 16 * scale * 0.85, i);
      GD.Vertex2f(x, y);
    }
  }

  // time-timer
  if ( minutes > 0 ) {
    Poly po;
    po.begin();
    po.v(centerx * 16, centery * 16);
    clock_ray(centerx, centery, x, y, 16 * scale * 0.7, 60 - minutes);
    po.v(x, y);
    clock_ray(centerx, centery, x, y, 16 * scale * 0.7, (int)( 60 - minutes + 1 ));
    po.v(x, y);
    GD.ColorRGB(COLOR_RED);
    po.draw();
    for (int i = 60 - minutes + 1; i < 60; i++) {
      Poly po;
      po.begin();
      po.v(centerx * 16, centery * 16);
      clock_ray(centerx, centery, x, y, 16 * scale * 0.7, i + 1.1);
      po.v(x, y);
      clock_ray(centerx, centery, x, y, 16 * scale * 0.7, i - 0.1);
      po.v(x, y);
      GD.ColorRGB(COLOR_RED);
      po.draw();
    }
  }

}

int job2jpg( String job ) {
  if ( job == "bril" )
    return BRIL_JPG;
  else if ( job == "douchen" )
    return DOUCHEN_JPG;
  else if ( job == "drinken" )
    return DRINKEN_JPG;
  else if ( job == "haar" )
    return HAAR_JPG;
  else if ( job == "huiswerk" )
    return HUISWERK_JPG;
  else if ( job == "kaka" )
    return KAKA_JPG;
  else if ( job == "kine" )
    return KINE_JPG;
  else if ( job == "klussen" )
    return KLUSSEN_JPG;
  else if ( job == "opruimen" )
    return LEGOPRUM_JPG;
  else if ( job == "lezen" )
    return LEZEN_JPG;
  else if ( job == "nagels" )
    return NAGELS_JPG;
  else if ( job == "nopanic" )
    return NOPANIC_JPG;
  else if ( job == "pillen" )
    return PILLEN_JPG;
  else if ( job == "pipikaka" )
    return PIPIKAKA_JPG;
  else if ( job == "pompen" )
    return POMPEN_JPG;
  else if ( job == "pyjama" )
    return PYJAMA_JPG;
  else if ( job == "tanden" )
    return TANDEN_JPG;
  else if ( job == "uitmesten" )
    return UITMEST_JPG;
  else if ( job == "wasmand" )
    return WASMAND_JPG;
  return -1;
}

void display_time_timer( double minutes ) {
  int jpg = job2jpg( current_job_string );
  if ( jpg != -1 ) {
    GD.Begin(BITMAPS);
    GD.ColorRGB(COLOR_BEIGE);
    GD.Vertex2ii(GD.w / 2 + GD.w / 4 - 50, GD.h / 2 - 50, jpg );
    GD.ColorRGB(COLOR_BLACK);
    GD.cmd_text(GD.w / 2 + GD.w / 4, GD.h / 2 + 60, 28, OPT_CENTER, current_job_string);
    show_time_timer( minutes, GD.w / 2 - GD.w / 4 + 50, GD.h / 2, 100 );
  } else {
    GD.cmd_text(GD.w / 2, GD.h - 20, 28, OPT_CENTER, current_job_string);
    show_time_timer( minutes, GD.w / 2 - 10, GD.h / 2, 100 );
  }
}

void run_time_timer() {

  DateTime now = rtc.now();
  double minutes = (time_timer - now.unixtime()) / (double)SECONDS_PER_MINUTE;
  display_time_timer( minutes );
  if ( now.unixtime() >= time_timer ) {
    state = FINISHED_STATE;
  }
}

long next_alarm_bleep = 0;
void show_timer_finished() {

  DateTime now = rtc.now();

  if ( now.unixtime() >= next_alarm_bleep ) {
    next_alarm_bleep = now.unixtime() + 2;
    jingle();
  }

  GD.get_inputs();
  switch (GD.inputs.tag) {
    case 201:
      strcpy(current_job_string, "");
      points++;
      goed1 = rand() % 16;
      goed2 = rand() % 16;
      state = GOED_GEDAAN_STATE;
      delay(200);
      break;
  }

  GD.ColorRGB(COLOR_BLACK);
  GD.cmd_fgcolor(COLOR_GREEN);
  GD.Tag(201);
  GD.cmd_button( GD.w - 90, GD.h - 60, 80, 50, 27, OPT_FLAT, "OK" );

  display_time_timer( 0 );
  //  show_time_timer( 0, GD.w / 2, GD.h / 2, 100 );

}

void statusbar( int hour, int minute, int second ) {

  GD.ColorA(128);

  // update WiFi status
  //if ( WiFi.status() == WL_CONNECTED ) GD.ColorRGB(COLOR_GREEN); else GD.ColorRGB(COLOR_RED);
  //GD.cmd_text(5, 5, 20, 0, "Wifi");
  // update MQTT status
  client.loop();
  if ( client.connected() ) {
    GD.ColorRGB(COLOR_GREEN); 
    GD.cmd_text(5, 5, 20, 0, "Online");
  } else {
    GD.ColorRGB(COLOR_RED);
    GD.cmd_text(5, 5, 20, 0, "Offline");
  }
    
  GD.ColorRGB(COLOR_BEIGE);
  GD.cmd_text(GD.w / 2, 12, 20, OPT_CENTER, person);

  String time = format_time( hour, minute, second );
  GD.ColorRGB(COLOR_BLACK);
  GD.cmd_text(GD.w - 65, 5, 20, 0, string2char(time));
  GD.ColorA(255);
}

bool play_sample_next = false;
bool play_sample_next_next = false; // dirty, dirty hack but I must move fast
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
void loop() {

  DateTime now = rtc.now();
  double minutes = (time_timer - now.unixtime()) / (double)SECONDS_PER_MINUTE;
  int current_h = now.hour();
  int current_m = now.minute();
  int current_s = now.second();

  // clear screen
  uint32_t bgcolor = COLOR_BEIGE;
  switch (state) {
    case CLOCK_STATE:
    case SHOW_LOG_STATE:
      bgcolor = COLOR_BLACK;
      break;
    case REMINDER_STATE:
      bgcolor = COLOR_YELLOW;
      break;
    case ALARM_STATE:
      bgcolor = COLOR_RED;
      break;
    case GOED_GEDAAN_STATE:
      bgcolor = COLOR_GREEN;
      break;
  }
  GD.ClearColorRGB(bgcolor);
  GD.Clear();

  // always show the statusbar
  statusbar( current_h, current_m, current_s );

  // dependent on state, show contents
  switch (state) {
    case FINISHED_STATE:
      show_timer_finished();
      break;
    case REMINDER_STATE:
      show_reminder( current_job_string );
      break;
    case ALARM_STATE:
      show_alarm( current_job_string );
      break;
    case TIME_TIMER_STATE:
      run_time_timer();
      break;
    case UPCOMING_STATE:
      show_upcoming_events();
      break;
    case SHOW_LOG_STATE:
      GD.ColorRGB(COLOR_BEIGE);
      show_log();
      break;
    case CLOCK_STATE:
      int cache_time;
      cache_time = current_h * 10000 + current_m * 100 + current_s;
      if ( cache.count( cache_time ) ) {
        parse_command(string2char(cache[cache_time]));
        cache.erase(cache_time);
      }
      show_clock();
      if( current_h == 1 ) points = 1;
      break;
    case TODO_STATE:
      show_todo();
      break;
    case GOED_GEDAAN_STATE:
      show_goed_gedaan();
      break;
  }

  // bring the contents to the front
  GD.swap();

  // dirty hack to play a sample in the next frame
  if( play_sample_next_next )
    sample();
  play_sample_next_next = play_sample_next;
  play_sample_next = false;


  // make sure we're still connected to MQTT
  mqttOnlineCheck();
  // keep generating random numbers to mess with the seed
  rand();

}

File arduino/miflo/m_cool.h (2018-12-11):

/*************************************************
 * Public Constants
 *************************************************/

#define NOTE_B0  31
#define NOTE_C1  33
#define NOTE_CS1 35
#define NOTE_D1  37
#define NOTE_DS1 39
#define NOTE_E1  41
#define NOTE_F1  44
#define NOTE_FS1 46
#define NOTE_G1  49
#define NOTE_GS1 52
#define NOTE_A1  55
#define NOTE_AS1 58
#define NOTE_B1  62
#define NOTE_C2  65
#define NOTE_CS2 69
#define NOTE_D2  73
#define NOTE_DS2 78
#define NOTE_E2  82
#define NOTE_F2  87
#define NOTE_FS2 93
#define NOTE_G2  98
#define NOTE_GS2 104
#define NOTE_A2  110
#define NOTE_AS2 117
#define NOTE_B2  123
#define NOTE_C3  131
#define NOTE_CS3 139
#define NOTE_D3  147
#define NOTE_DS3 156
#define NOTE_E3  165
#define NOTE_F3  175
#define NOTE_FS3 185
#define NOTE_G3  196
#define NOTE_GS3 208
#define NOTE_A3  220
#define NOTE_AS3 233
#define NOTE_B3  247
#define NOTE_C4  262
#define NOTE_CS4 277
#define NOTE_D4  294
#define NOTE_DS4 311
#define NOTE_E4  330
#define NOTE_F4  349
#define NOTE_FS4 370
#define NOTE_G4  392
#define NOTE_GS4 415
#define NOTE_A4  440
#define NOTE_AS4 466
#define NOTE_B4  494
#define NOTE_C5  523
#define NOTE_CS5 554
#define NOTE_D5  587
#define NOTE_DS5 622
#define NOTE_E5  659
#define NOTE_F5  698
#define NOTE_FS5 740
#define NOTE_G5  784
#define NOTE_GS5 831
#define NOTE_A5  880
#define NOTE_AS5 932
#define NOTE_B5  988
#define NOTE_C6  1047
#define NOTE_CS6 1109
#define NOTE_D6  1175
#define NOTE_DS6 1245
#define NOTE_E6  1319
#define NOTE_F6  1397
#define NOTE_FS6 1480
#define NOTE_G6  1568
#define NOTE_GS6 1661
#define NOTE_A6  1760
#define NOTE_AS6 1865
#define NOTE_B6  1976
#define NOTE_C7  2093
#define NOTE_CS7 2217
#define NOTE_D7  2349
#define NOTE_DS7 2489
#define NOTE_E7  2637
#define NOTE_F7  2794
#define NOTE_FS7 2960
#define NOTE_G7  3136
#define NOTE_GS7 3322
#define NOTE_A7  3520
#define NOTE_AS7 3729
#define NOTE_B7  3951
#define NOTE_C8  4186
#define NOTE_CS8 4435
#define NOTE_D8  4699
#define NOTE_DS8 4978

// This file was generated with the command-line:
//    /usr/local/bin/gd3asset -3 -f genflo.gd2 -o genflo.h f_dduim.wav f_wauw.wav f_bol.wav f_uitst.wav f_go.wav f_komaan.wav g_cool.wav g_formid.wav g_machti.wav g_stieva.wav g_woew.wav g_dduim2.wav g_goed.wav g_muppet.wav g_super.wav g_woop.wav g_allez.wav g_demax.wav g_goedzo.wav g_prima.wav g_tsjing.wav g_zogoed.wav g_bol.wav g_fantas.wav g_hopla.wav g_scool.wav g_wiii.wav

#define F_DDUIM 0UL
#define F_DDUIM_LENGTH 26496
#define F_DDUIM_FREQ 44100
#define F_WAUW 26496UL
#define F_WAUW_LENGTH 24768
#define F_WAUW_FREQ 44100
#define F_BOL 51264UL
#define F_BOL_LENGTH 43776
#define F_BOL_FREQ 44100
#define F_UITST 95040UL
#define F_UITST_LENGTH 31680
#define F_UITST_FREQ 44100
#define F_GO 126720UL
#define F_GO_LENGTH 19008
#define F_GO_FREQ 44100
#define F_KOMAAN 145728UL
#define F_KOMAAN_LENGTH 25920
#define F_KOMAAN_FREQ 44100
#define G_COOL 171648UL
#define G_COOL_LENGTH 14976
#define G_COOL_FREQ 44100
#define G_FORMID 186624UL
#define G_FORMID_LENGTH 23040
#define G_FORMID_FREQ 44100
#define G_MACHTI 209664UL
#define G_MACHTI_LENGTH 27648
#define G_MACHTI_FREQ 44100
#define G_STIEVA 237312UL
#define G_STIEVA_LENGTH 16128
#define G_STIEVA_FREQ 44100
#define G_WOEW 253440UL
#define G_WOEW_LENGTH 33408
#define G_WOEW_FREQ 44100
#define G_DDUIM2 286848UL
#define G_DDUIM2_LENGTH 19008
#define G_DDUIM2_FREQ 44100
#define G_GOED 305856UL
#define G_GOED_LENGTH 21888
#define G_GOED_FREQ 44100
#define G_MUPPET 327744UL
#define G_MUPPET_LENGTH 31680
#define G_MUPPET_FREQ 44100
#define G_SUPER 359424UL
#define G_SUPER_LENGTH 42624
#define G_SUPER_FREQ 44100
#define G_WOOP 402048UL
#define G_WOOP_LENGTH 17280
#define G_WOOP_FREQ 44100
#define G_ALLEZ 419328UL
#define G_ALLEZ_LENGTH 23616
#define G_ALLEZ_FREQ 44100
#define G_DEMAX 442944UL
#define G_DEMAX_LENGTH 18432
#define G_DEMAX_FREQ 44100
#define G_GOEDZO 461376UL
#define G_GOEDZO_LENGTH 20160
#define G_GOEDZO_FREQ 44100
#define G_PRIMA 481536UL
#define G_PRIMA_LENGTH 12096
#define G_PRIMA_FREQ 44100
#define G_TSJING 493632UL
#define G_TSJING_LENGTH 38592
#define G_TSJING_FREQ 44100
#define G_ZOGOED 532224UL
#define G_ZOGOED_LENGTH 17856
#define G_ZOGOED_FREQ 44100
#define G_BOL 550080UL
#define G_BOL_LENGTH 38016
#define G_BOL_FREQ 44100
#define G_FANTAS 588096UL
#define G_FANTAS_LENGTH 25920
#define G_FANTAS_FREQ 44100
#define G_HOPLA 614016UL
#define G_HOPLA_LENGTH 12672
#define G_HOPLA_FREQ 44100
#define G_SCOOL 626688UL
#define G_SCOOL_LENGTH 27072
#define G_SCOOL_FREQ 44100
#define G_WIII 653760UL
#define G_WIII_LENGTH 30528
#define G_WIII_FREQ 44100
#define ASSETS_END 684288UL
#define LOAD_ASSETS()  (GD.safeload("genflo.gd2"), GD.loadptr = ASSETS_END)

struct {
} bitmaps = {

};

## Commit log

2018-05-04 reset points at 1 at night
    [miflo.ino]
2018-05-04 odds and ends, ie, control shutdown of speaker with pin 15
2018-05-04 dirty hack to play a sample after the next frame is rendered
2018-12-03 arduino code
2018-12-03 hardware BOM en PCB
    [miflo.brd, miflo.sch]
2018-12-03 3d print files
2018-12-03 arduino readme
2018-12-09 update of arduino readme and settings example

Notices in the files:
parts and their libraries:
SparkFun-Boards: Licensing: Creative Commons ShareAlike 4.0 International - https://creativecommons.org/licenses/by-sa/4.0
